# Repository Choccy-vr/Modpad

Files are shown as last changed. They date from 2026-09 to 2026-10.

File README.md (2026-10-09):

# Modpad
> An open-source, hot-swappable modular macro pad system with live browser-based key mapping.

Modpad combines hardware and software to create an adaptable modular macropad. Rather than locking users in a fixed, rigid layout, keyboard layout, or proprietary config software, Modpad allows users to magnetically hot-swap satellite modules into a main module and reconfigure key actions and layout all in real time.

Configurator URL: https://modpad.vercel.app/

BUILT IMAGE HERE
---
## Features
- **Dynamic Module Discovery:** Automatically identifies and polls attached satellite modules using i2c
- **Zero-Install Configurator:** Uses web serial to read active layouts, update bindings, and provide real-time input status all with a website.
- **Dynamic Remapping:** Keymaps are refreshed directly in the microcontroller's RAM; no need to restart every time.
- **Full HID & Consumer Control Support:** Emulates standard keyboard keystrokes, modifiers, and media controls (Volume, Play/Pause, Brightness).

## Modules
- **Macro:** The standard-sized macro pad. 6 completely remappable buttons.
- **Knobs:** 2 Rotary Encoders. Perfect for volume and brightness.
- More in the works

## Protocol
The web configurator and the main module communicate over USB serial (115200 baud) using newline-delimited JSON. Each message is a single JSON object ending in `\n`.

| Message | Direction | Description | Example |
|---|---|---|---|
| `get_layout` | Web -> Board | Requests the keymap of every module | `{"cmd":"get_layout"}` |
| `layout` | Board -> Web | Returns each module's keymap as a list of actions | `{"status":"layout","modules":{"Macro":[{"code":4,"mod":0,"consumer":false}, ...]}}` |
| `get_modules` | Web -> Board | Requests which modules are currently connected | `{"cmd":"get_modules"}` |
| `modules` | Board -> Web | Returns the connection state of each module | `{"status":"modules","modules":{"Macro":true,"Knobs":false}}` |
| `set_key` | Web -> Board | Rebinds one key or knob direction in RAM | `{"cmd":"set_key","module":"Macro","index":2,"code":4,"modifiers":0,"consumer":false}` |
| `ok` / `error` | Board -> Web | Reply to `set_key` | `{"status":"ok"}` / `{"status":"error","msg":"invalid_key_or_module"}` |
| `press` | Board -> Web | Sent whenever a button or knob is used | `{"status":"press","module":{"name":"Macro","index":2,"type":"button"}}` |
| `log` | Board -> Web | Debug message, so the serial stream stays pure JSON | `{"status":"log","msg":"..."}` |

### Fields
- `code`: HID keyboard usage ID, or a consumer usage ID when `consumer` is `true` (for example `0xE9` for Volume +).
- `modifiers` / `mod`: Modifier bitmask (`0x01` LCtrl, `0x02` LShift, `0x04` LAlt, `0x08` LGui, `0x10` RCtrl, `0x20` RShift, `0x40` RAlt, `0x80` RGui).
- `index`: Position in the module's keymap. It's the same index for `set_key` and `press`.

---

---
## Pictures
### Configurator


### Main Module
#### Schematic


#### PCB


#### PCB 3D model



#### CAD

Modpad_2026-Oct-04_01-32-06AM-000_CustomizedView5351986487

### Macro Module
#### Schematic


#### PCB


#### PCB 3D model




#### CAD

b51b9fef-189e-4e89-835a-75f2742f794a

### Knobs Module
#### Schematic


#### PCB


#### PCB 3D model



#### CAD

a1f602ed-3c62-45a9-a582-e62301d659ef

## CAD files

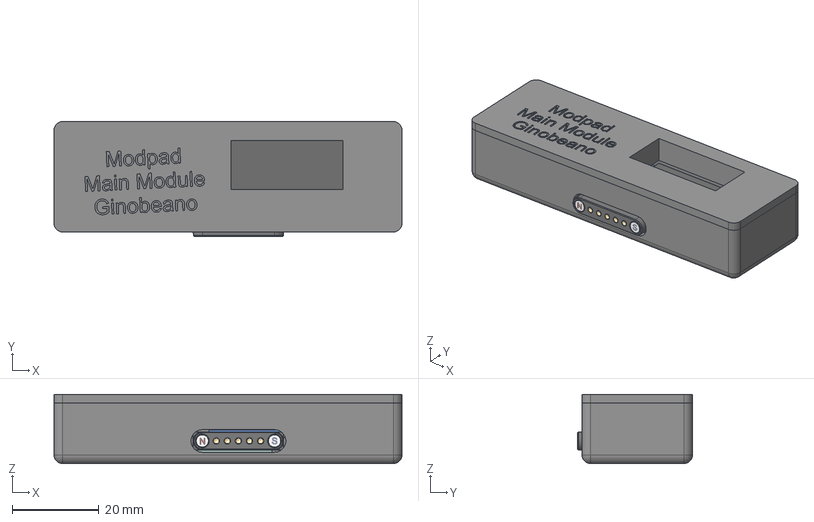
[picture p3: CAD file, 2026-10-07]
CAD/Modpad-Main.step
80.0 x 26.4 x 15.9 mm
OLED_0.91_128x32
Pin Header 4 x 1 TH 2.54mm Pitch
RESC-0603 x 13
2SD0601A
R_0805_2012Metric_2 x 2
modC695_PCB
RP2040-ZERO-WAVESHARE with headers
Magnetic Pogo Connector 5 Pin (Type 3)
Main-Module-Housing

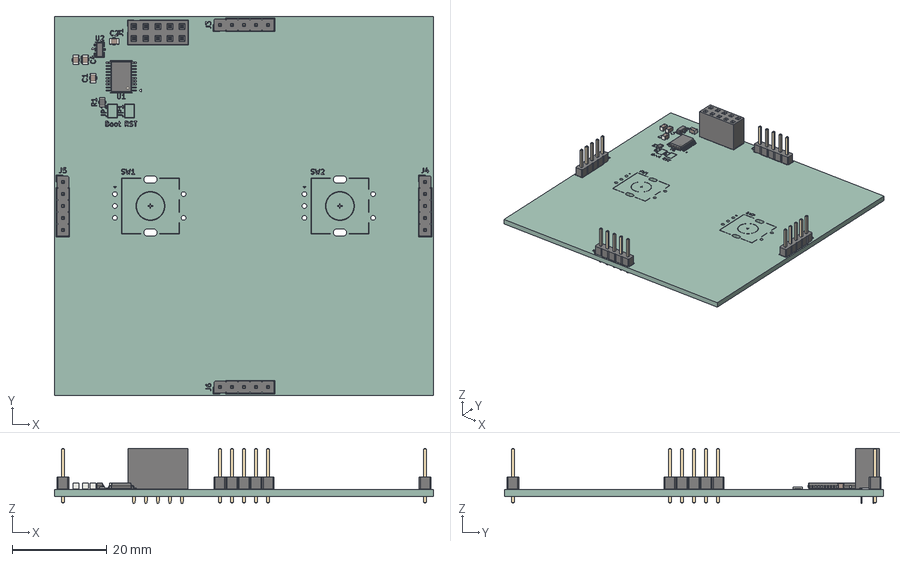
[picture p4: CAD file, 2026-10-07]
PCB/knobs_module[/knobs_module.step
80.0 x 80.0 x 11.6 mm
PinHeader_1x05_P254mm_Vertical x 4
R_0805_2012Metric
C_0805_2012Metric x 4
PinSocket_2x05_P2.54mm_Vertical
TSSOP-20_4.4x6.5mm_P0.65mm
SOT-23-3
knoED99_silkscreen x 2
knoED99_PCB

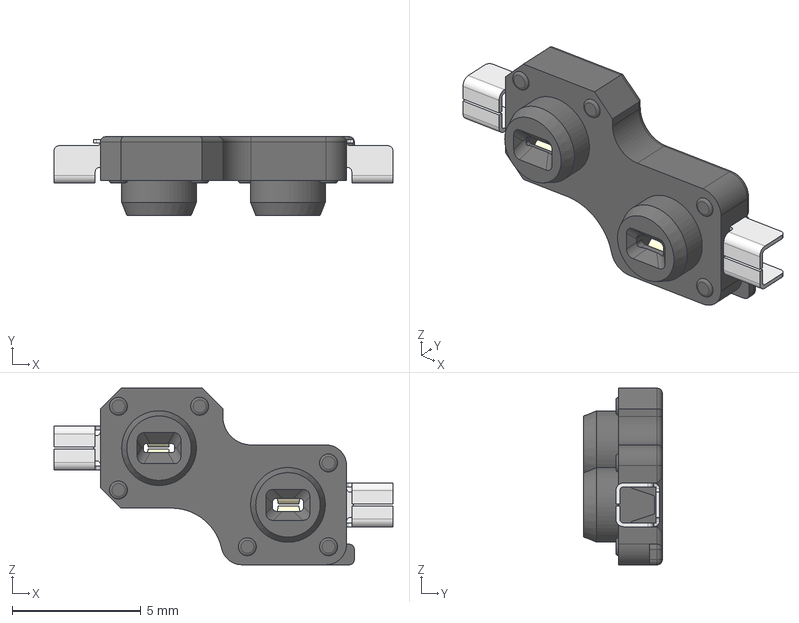
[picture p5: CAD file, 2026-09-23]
PCB/Resources/MX_V2-main/3D/Kailh-Choc-Socket-CPG135001S30.step
13.1 x 3.05 x 6.85 mm
Insert 2
Insert 1

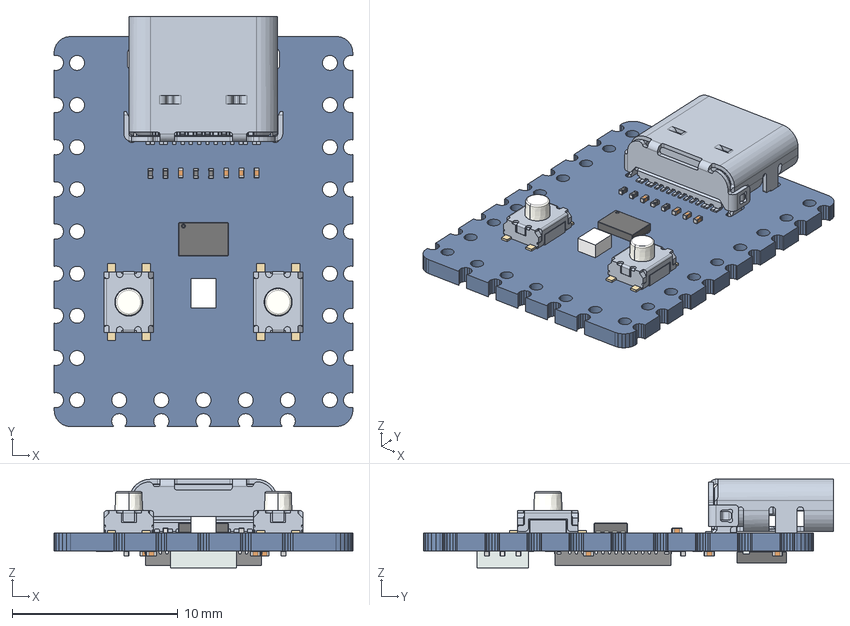
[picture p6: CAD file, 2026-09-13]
PCB/Resources/RP2040-Zero-Kicad-main/RP2040_Zero.stp
18.0 x 24.7 x 5.34 mm
BOARD
ANSCHL_X_FCSSE_1 x 9
K_X_F6RPER_1 x 9
EXTRUDED-32530
USER_LIBRARY-CHIP_CAP_MLCC_0201 x 19
EXTRUDED-36548
USER_LIBRARY-RP2040_QFN56_04
USER_LIBRARY-8MA3_1
USER_LIBRARY-8MA3_2
EXTRUDED-175432
EXTRUDED-175804 x 5
TS-1185EC-A-E-A-1 x 2
EXTRUDED-374538 x 10

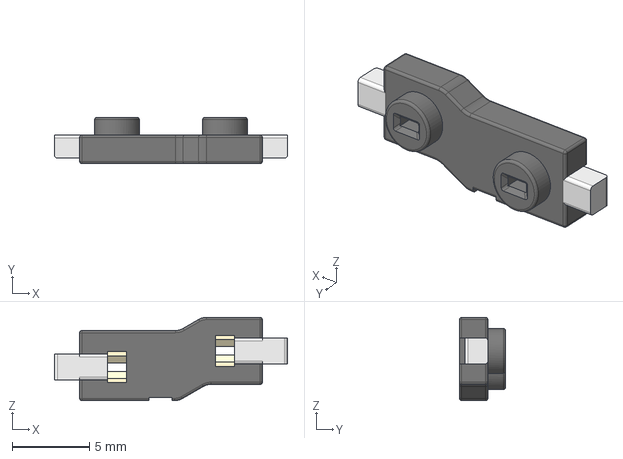
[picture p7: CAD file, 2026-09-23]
PCB/Resources/MX_V2-main/3D/Gateron-KS33-Socket.step
15.1 x 3.00 x 5.40 mm

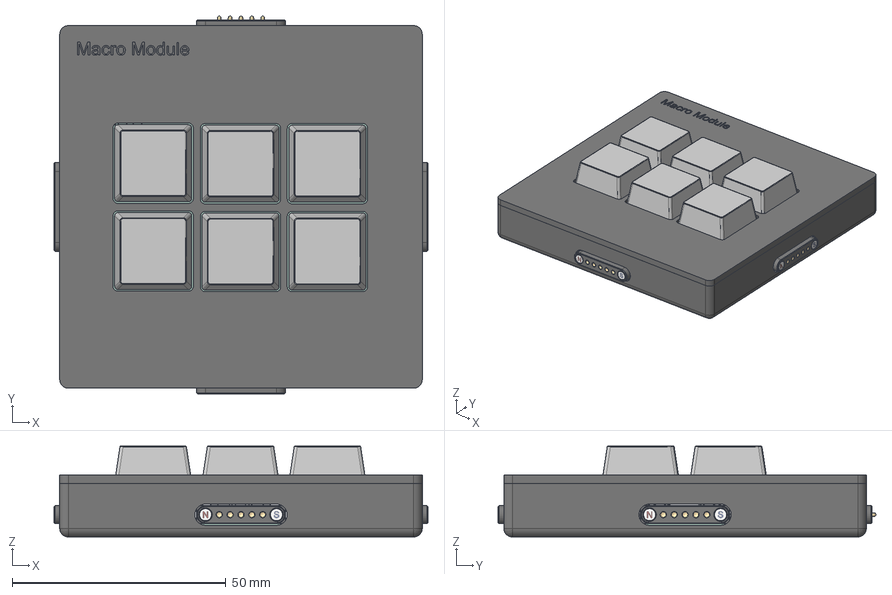
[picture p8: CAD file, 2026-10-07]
CAD/Modpad-Macro.step
87.5 x 88.4 x 21.3 mm
R_0805_2012Metric_1
C_0805_2012Metric_4 x 4
TSSOP-20_4.4x6.5mm_P0.65mm_1
SOT-23-3_1
mac8A13_silkscreen
mac8A13_silkscreen_1
mac8A13_PCB
Magnetic Pogo Connector 5 Pin (Type 3) x 3
MX Series-Cherry Key x 6
Magnetic Pogo Connector 5 Pin (Type 4)
beschr. Kappe Abdeckung x 6
beschr. Kappe Unterteil x 6
Macro-Module-Housing

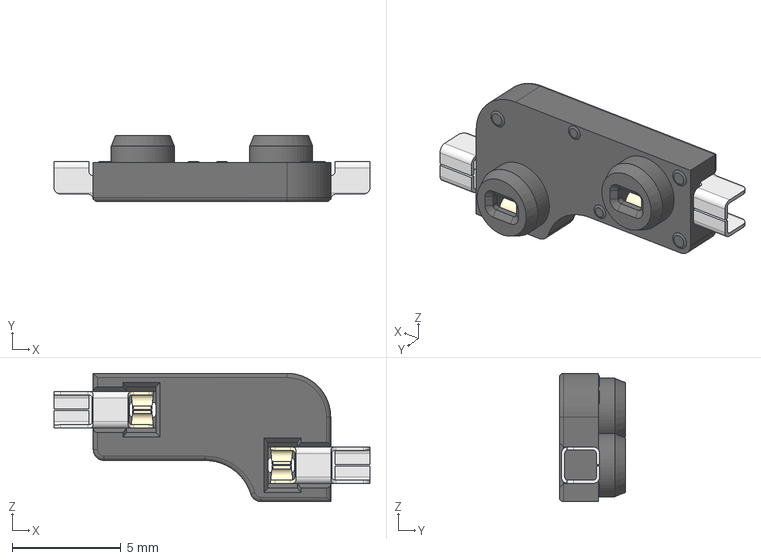
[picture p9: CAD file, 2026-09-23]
PCB/Resources/MX_V2-main/3D/MX-Hotswap-Socket.step
14.5 x 3.05 x 5.89 mm

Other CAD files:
PCB/macro_module/macro_module.step
CAD/Knobs.step

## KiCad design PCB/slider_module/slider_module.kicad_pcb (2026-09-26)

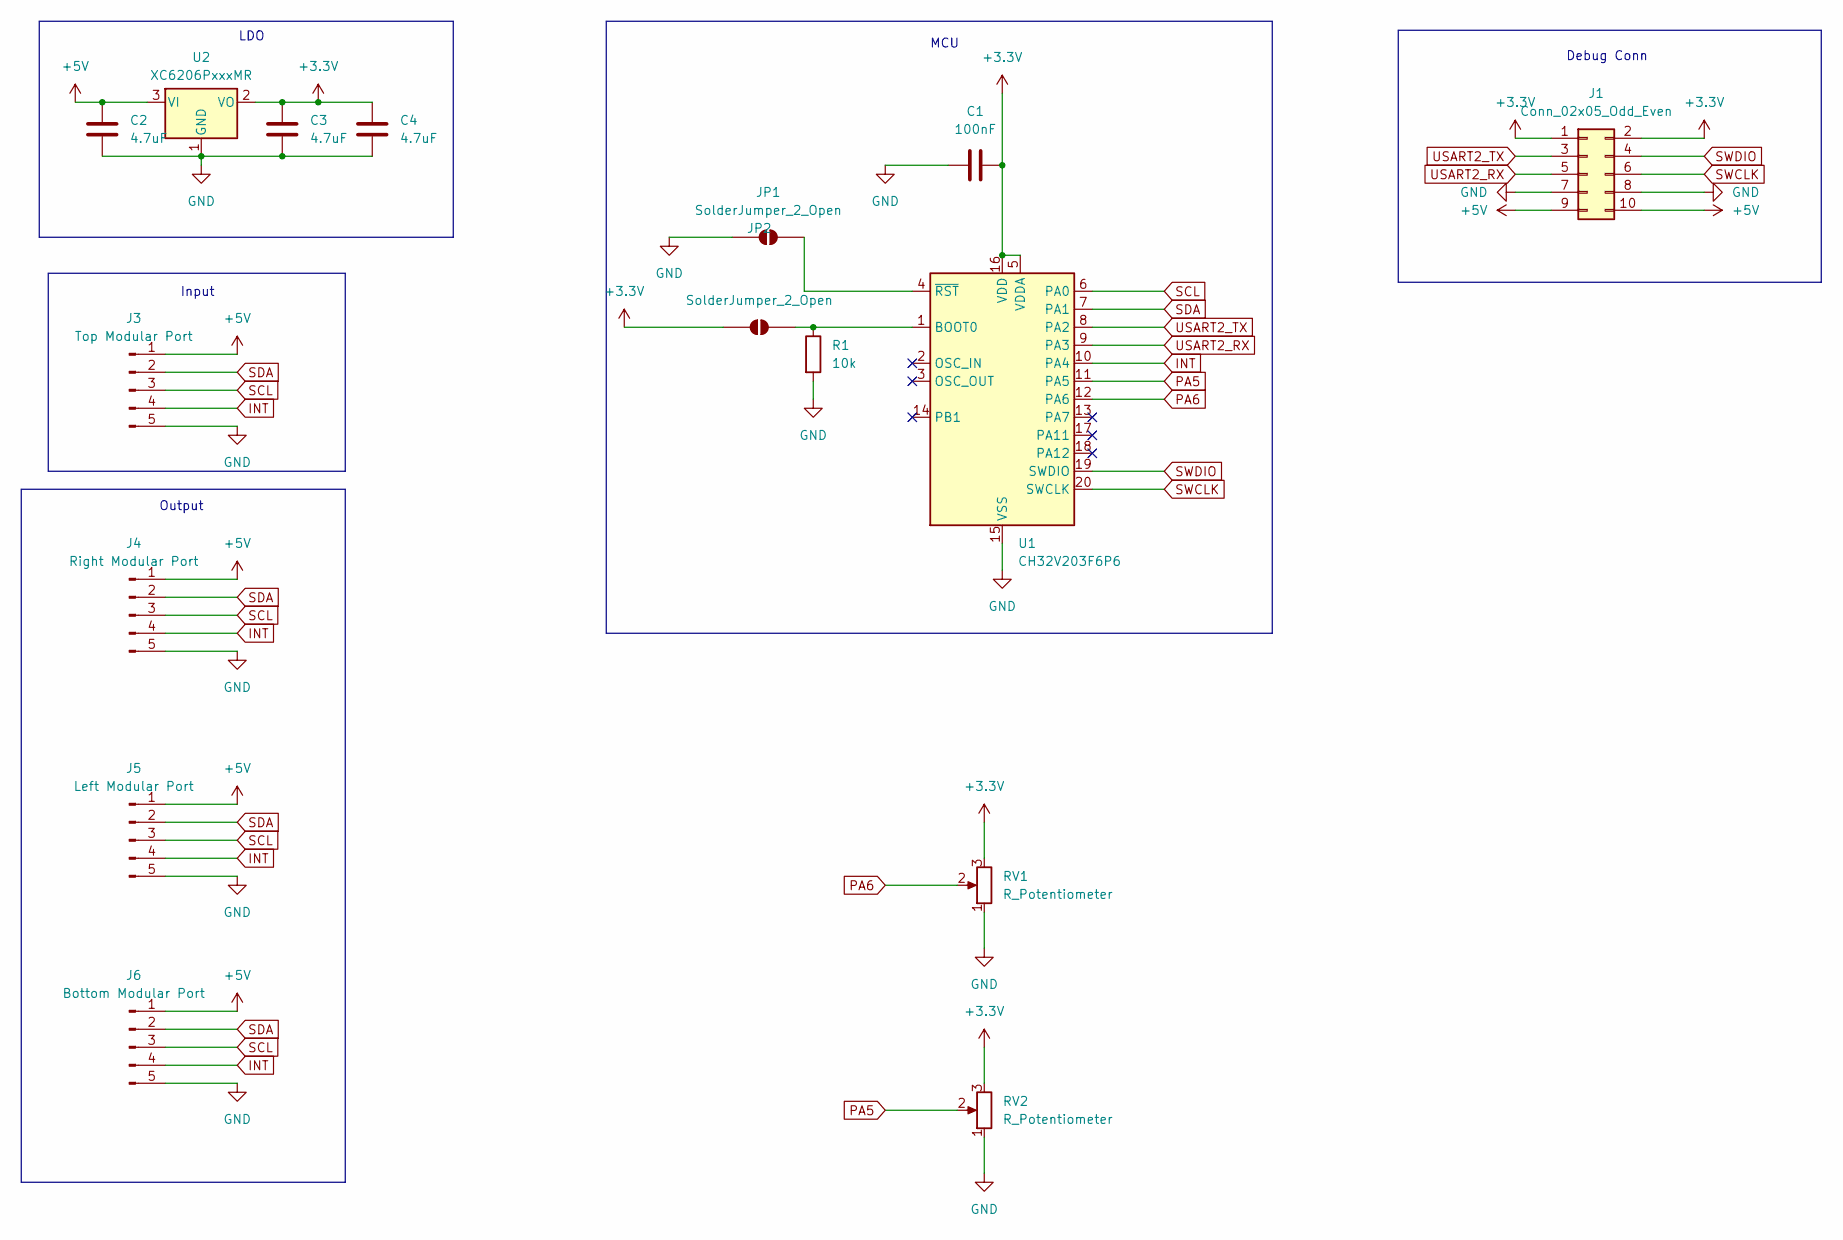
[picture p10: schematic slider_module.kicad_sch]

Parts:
C1: 100nF; C_0805_2012Metric
C2, C3, C4: 4.7uF; C_0805_2012Metric
J1: Conn_02x05_Odd_Even; PinSocket_2x05_P2.54mm_Vertical
J3: Top Modular Port; PinHeader_1x05_P2.54mm_Vertical
J4: Right Modular Port; PinHeader_1x05_P2.54mm_Vertical
J5: Left Modular Port; PinHeader_1x05_P2.54mm_Vertical
J6: Bottom Modular Port; PinHeader_1x05_P2.54mm_Vertical
JP1, JP2: SolderJumper_2_Open; SolderJumper-2_P1.3mm_Open_Pad1.0x1.5mm
R1: 10k; R_0805_2012Metric
RV1, RV2: R_Potentiometer; Potentiometer_Bourns_PTA4543_Single_Slide
U1: CH32V203F6P6; TSSOP-20_4.4x6.5mm_P0.65mm
U2: XC6206PxxxMR; SOT-23-3

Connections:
+3.3V: C1.2, C3.1, C4.1, J1.1, J1.2, JP2.1 (A), RV1.3, RV2.3, U1.5 (VDDA), U1.16 (VDD), U2.2 (VO)
+5V: C2.1, J1.9, J1.10, J3.1, J4.1, J5.1, J6.1, U2.3 (VI)
GND: C1.1, C2.2, C3.2, C4.2, J1.7, J1.8, J3.5, J4.5, J5.5, J6.5, JP1.1 (A), R1.2, RV1.1, RV2.1, U1.15 (VSS), U2.1 (GND)
INT: J3.4, J4.4, J5.4, J6.4, U1.10 (PA4)
unnamed: JP1.2 (B), U1.4 (~RST)
unnamed: JP2.2 (B), R1.1, U1.1 (BOOT0)
PA5: RV2.2, U1.11 (PA5)
PA6: RV1.2, U1.12 (PA6)
SCL: J3.3, J4.3, J5.3, J6.3, U1.6 (PA0)
SDA: J3.2, J4.2, J5.2, J6.2, U1.7 (PA1)
SWCLK: J1.6, U1.20 (SWCLK)
SWDIO: J1.4, U1.19 (SWDIO)
USART2_RX: J1.5, U1.9 (PA3)
USART2_TX: J1.3, U1.8 (PA2)

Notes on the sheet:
Debug Conn
Input
Output
LDO
MCU

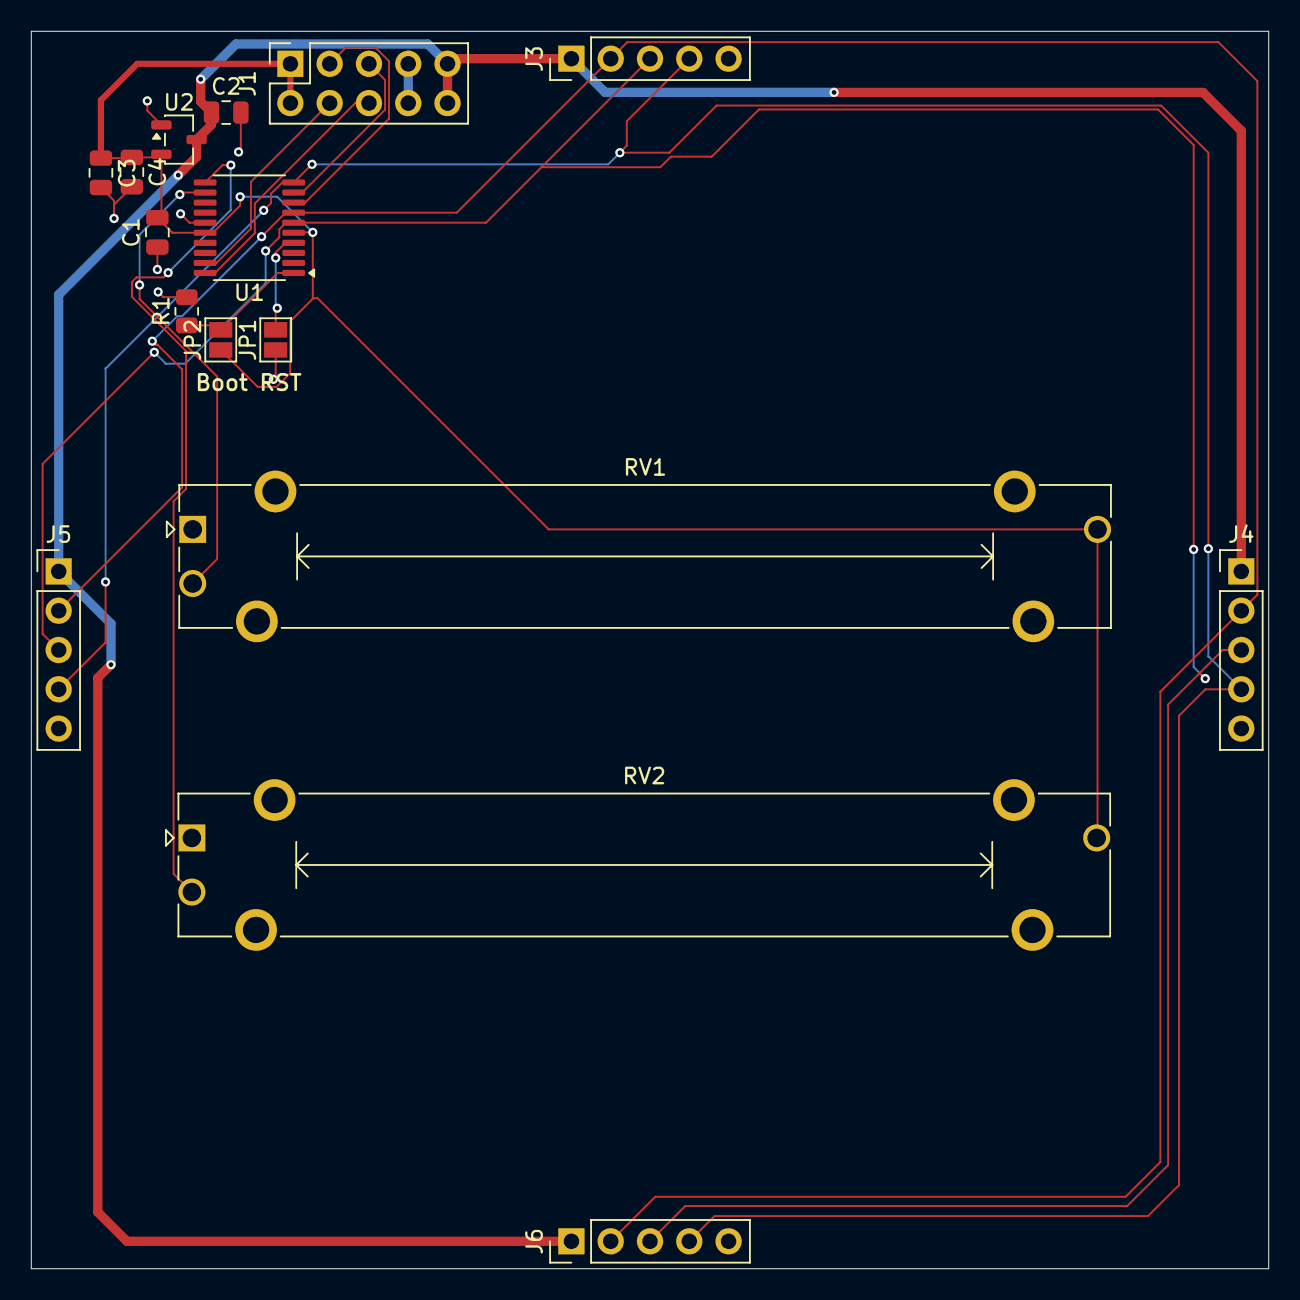
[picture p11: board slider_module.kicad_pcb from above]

Board: 2 copper layers, 80.0 x 80.0 mm, 16 parts (0 on the bottom side), 14 nets.

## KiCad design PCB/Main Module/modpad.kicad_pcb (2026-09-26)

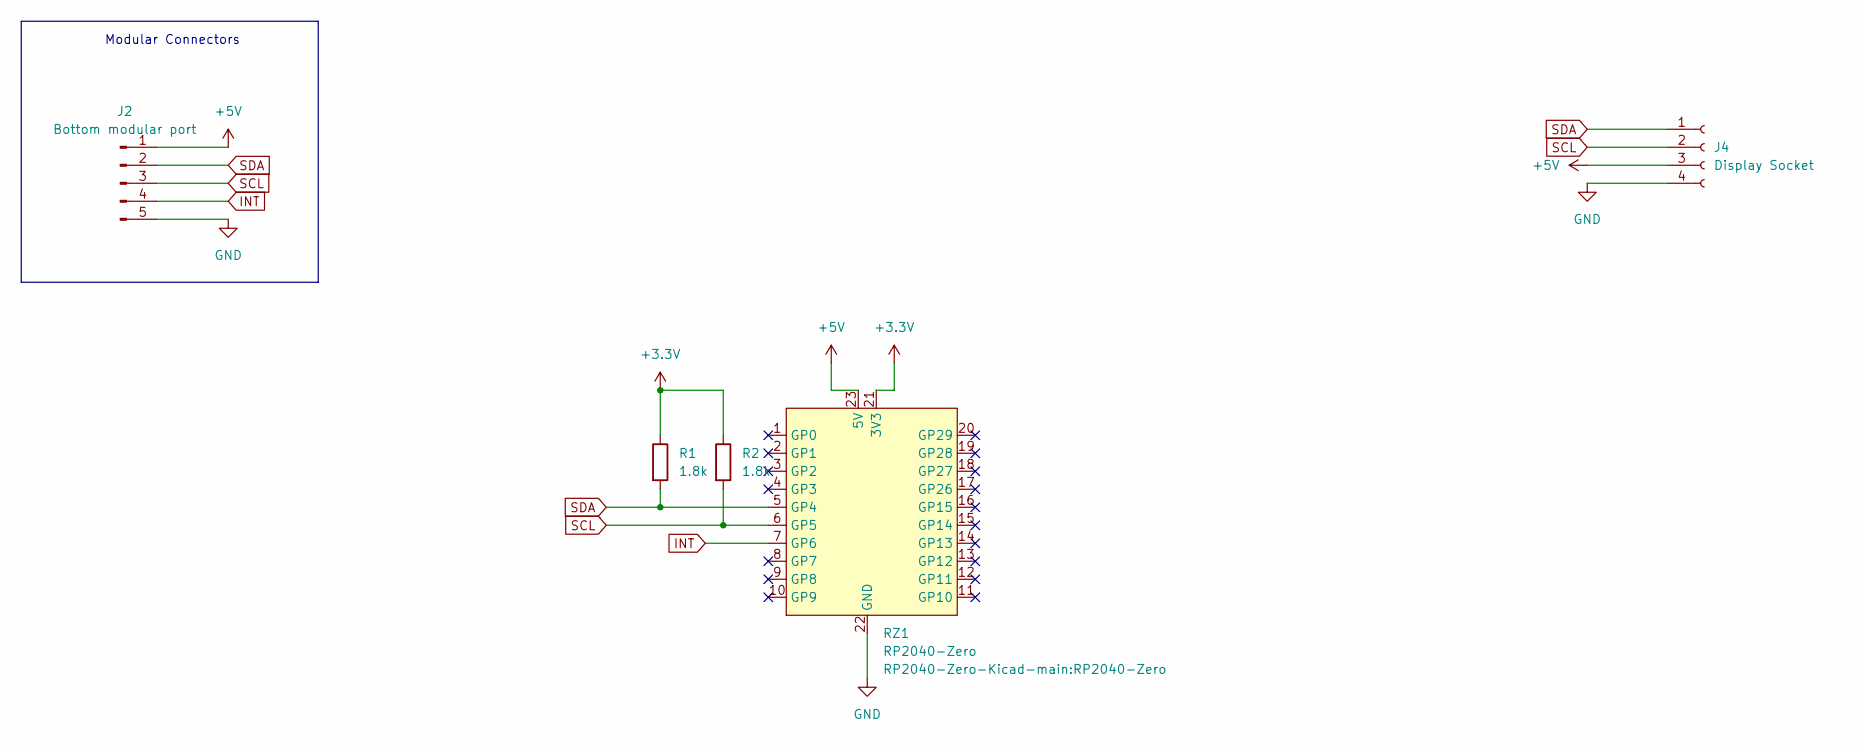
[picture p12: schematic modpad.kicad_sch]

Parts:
J2: Bottom modular port; PinHeader_1x05_P2.54mm_Vertical
J4: Display Socket; SSD1306-0.91-OLED-4pin-128x32
R1, R2: 1.8k; R_0805_2012Metric
RZ1: RP2040-Zero

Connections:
+3.3V: R1.1, R2.1, RZ1.21 (3V3)
+5V: J2.1, J4.3, RZ1.23 (5V)
GND: J2.5, J4.4, RZ1.22 (GND)
INT: J2.4, RZ1.7 (GP6)
SCL: J2.3, J4.2, R2.2, RZ1.6 (GP5)
SDA: J2.2, J4.1, R1.2, RZ1.5 (GP4)

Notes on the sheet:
Modular Connectors

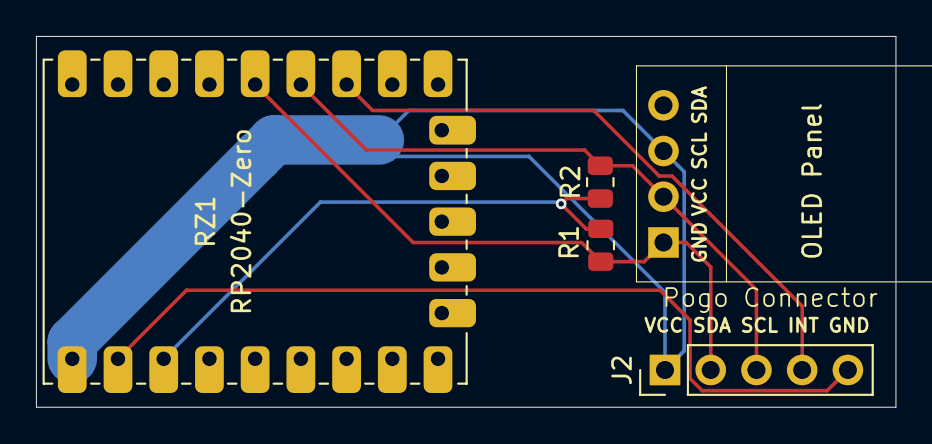
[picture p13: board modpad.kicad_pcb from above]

Board: 2 copper layers, 47.7 x 20.6 mm, 5 parts (0 on the bottom side), 6 nets.

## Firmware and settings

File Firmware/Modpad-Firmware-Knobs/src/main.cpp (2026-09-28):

#include <Arduino.h>
#include "Modules/Modules.h"

// index in this array is the encoder id sent to the main module
Encoder encoders[] = {
    {1, 2, false, 0, 0},
    {3, 27, false, 0, 0},
};
const size_t NUM_ENCODERS = sizeof(encoders) / sizeof(encoders[0]);

const int8_t QUAD_TABLE[16] = {0, -1, 1, 0, 1, 0, 0, -1, -1, 0, 0, 1, 0, 1, -1, 0};
const uint8_t DETENT_STATE = 0b11;

uint8_t readEncoder(const Encoder &e)
{
  return (digitalRead(e.pinA) << 1) | digitalRead(e.pinB);
}

void setup()
{
  Serial.begin(115200);
  for (size_t i = 0; i < NUM_ENCODERS; i++)
  {
    pinMode(encoders[i].pinA, INPUT_PULLUP);
    pinMode(encoders[i].pinB, INPUT_PULLUP);
    encoders[i].lastState = readEncoder(encoders[i]);
  }

  ModpadModules::setup();
}

void loop()
{
  for (size_t i = 0; i < NUM_ENCODERS; i++)
  {
    Encoder &e = encoders[i];
    uint8_t state = readEncoder(e);
    if (state == e.lastState)
      continue;

    e.accum += QUAD_TABLE[(e.lastState << 2) | state];
    e.lastState = state;

    // only count a step once the knob settles in a detent
    if (state == DETENT_STATE)
    {
      if (e.accum >= 2 || e.accum <= -2)
      {
        bool cw = (e.accum > 0) != e.reversed;
        ModpadModules::stepEncoder(i, cw ? 0 : 1);
      }
      e.accum = 0;
    }
  }
}

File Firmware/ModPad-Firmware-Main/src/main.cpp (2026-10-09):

#include <Arduino.h>
#include <Adafruit_TinyUSB.h>
#include "HID/HID.h"
#include "Display/Display.h"
#include "Satelite/Satelite.h"
#include "Configurator/Configurator.h"
#include <Wire.h>

void setup()
{
    Serial.begin(115200);
    Wire1.setSDA(6);
    Wire1.setSCL(7);
    Wire1.begin();

    ModpadHID::setup();
    ModpadDisplay::setup();
    ModpadSatelite::setup();
}

void loop()
{
    ModpadSatelite::checkI2CEvent();
    ModpadSatelite::pollModulePresence();
    ModpadDisplay::update();
    ModpadConfigurator::processConfiguratorSerial();
}

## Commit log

2026-09-13 feat: modpad schematic v1
    [RP2040_Zero.stp, modpad.kicad_pcb, modpad.kicad_sch]
2026-09-14 feat(Main Module): PCB v1
    [modpad.kicad_pcb, modpad.kicad_sch]
2026-09-15 feat(templates): peripheral modules template draft
    [peripheral_module_template.kicad_pcb, peripheral_module_template.kicad_sch]
2026-09-23 feat:macro +knobs
    [knobs_module[.kicad_pcb, knobs_module[.kicad_sch, macro_module.kicad_pcb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]
2026-09-23 feat: finish macro module
    [Gateron-KS33-Socket.step, Kailh-Choc-Socket-CPG135001S30.step, MX-Hotswap-Socket.step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]
2026-09-26 feat: finish hardware designs
    [knobs_module[.kicad_pcb, macro_module.kicad_pcb, modpad.kicad_pcb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]
2026-09-27 fix: OLED code print out
    [main.cpp]
2026-09-28 feat(modules): implement button and encoder handling for satellite module
2026-10-04 Update README with new images and CAD section
    Added images and CAD section to README.
2026-10-06 Update README with additional images
    Added new images to the CAD and Knobs Module sections.
2026-10-07 Add CAD image to README
2026-10-07 feat: CAD
    [Knobs.step, Modpad-Macro.step, Modpad-Main.step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]
2026-10-21 feat: i2c drivers and other updates
